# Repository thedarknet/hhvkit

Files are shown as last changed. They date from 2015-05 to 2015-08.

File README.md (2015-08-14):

hhvkit
======

DefCon 23 Hardware Hacking Village Learn To Solder Kit, by:
- Smitty, mark@halibut.com (concept, crypto, and firmware (2014))
- Krux, krux@thcnet.net (hardware)
- Cmdc0de, comc0dez@gmail.com (firmware (2015))

These are the files needed to build the firmware for the DefCon DarkNet
ID Badge that was sold as the Hardware Hacking Village's Learn To Solder
kit at DefCon 23 in 2015.

If you checkout the repo into your Arduino folder, it should just build
on Arduino v1.6.4.  

It creates the following directories:

DCDarkNet/Firmware/
- Contains the code.

DCDarkNet/Firmware/build/
- The automated build/burn system used to program over 300 chips in 
  just a couple hours. (ZIF socket not included. Some assembly required.)

libraries/IRSerial2014/
- A modified version of SoftwareSerial from Arduino 1.0 (don't know if 
  it's changed at all in 1.5) to allow for independent inverted logic
  on the Rx and Tx lines (so the idle state isn't HIGH on the IR LED
  and burn through battery), and to perform 38kHz modulation for the IR.

libraries/UsbKeyboard/
- A version of vusb-for-arduino [1] modified so it doesn't instantiate
  the USB object in the .h file and therefore immeidately upon startup.
  Instead, you instantiate the object whenever you want it and can
  delete it when you're done.
  [1] https://code.google.com/p/vusb-for-arduino/

libraries/DarkNetDisplay
- Modified version of the adafruit gfx and ssd_1306 libraries to work with our 
  darknet badge display
	https://github.com/adafruit/Adafruit-GFX-Library
	https://github.com/adafruit/Adafruit_SSD1306

Building and Burning
======

All the following commands are run inside DCDarkNet/Firmware/build/
This section is really only relevant if you are burning this code into
a whole bunch of chips.  If you're just burning your own chip, or are
playing around with different code, you're better off just using the 
Arduino IDE to program the board directly with an FTDI cable.

Preparation: GUIDs and private keys
======
The code is programmed to FLASH, but there are a few things needed in
EEPROM before the badge is functional.  If you have a chip from us, it
was already programmed with your GUID and private key, which will persist
through a re-flash.  But if you have a new chip, you'll need to program
your GUID and private key into the chip.

We don't currently (2015-08-2) have a way to generate new GUIDs and 
keys for you, nor to take in GUIDs and keys from you to put into the DB.
So you're welcome to play with this code and use it for other things, 
but unless you got a chip from us at DefCon, you won't be able to 
use your code on the live DarkNet site (https://dcdark.net.)

If you're building a whole new name space and don't need to interact 
with the DefCon DarkNet Daemon, you can generate your own DB of random
GUIDs and private keys using the build/buildDB.pl script, and redirecting
the output to a file called DB.  This doesn't actually do anything with 
the chip, it just generates random numbers and formats them correctly.

build$ ./buildDB.pl > DB

Preparation: Program
=======
All the source code is compiled down into a .hex file by Arduino. Those
who do more microcontroller work than I do can build this by hand.  I'm 
lazy and let Arduino do all the drudgery for me.

Go to preferences and enable "verbose output of the build process" or
whatever it's called.  This will make Arduino NOT delete the temporary
build directories it creates in /tmp.  Then build the code with Ctrl-R.
That will burn into /tmp/build[some number].tmp/   Find the most recent
build directory (the one that was likely just created or updated), and
copy Firmware.cpp.hex to your build/ directory:

build$ cp /tmp/build[some number].tmp/Firmware.cpp.hex .

You will have to do this EVERY TIME you build.

Burning Chips
=======
The burn-bootloader.sh script assumes you have a USBtinyISP [2].  You'll
need to modify the avr-dude command if you have a different ISP.
[2] http://www.adafruit.com/product/46

Connect the USBtinyISP to the ICSP header on your board and run:

build$ ./burn-bootloader.sh

Congrats!  Your badge is now an Arduino!  It can be programmed through
the FTDI header as if it were an Uno.

But to make it a DarkNet ID Badge, it needs the GUID and private key in 
EEPROM, and the program in flash.

The burn-eeprom.sh script takes a GUID on the command line, pulls it 
and it's associated key from the "DB" file generated above, formats
them into a .hex file that avr-dude can burn to EEPROM, and burns it.
Again, you'll need the USBtinyISP plugged into the ICSP header:

build$ ./burn-eeprom.sh GUIDGUID

After those two are done, the program can be written to flash using
the FTDI serial console cable (it's much faster than using the ICSP.)
burn-flash.sh takes the local file Firmware.cpp.hex you copied 
above.

build$ ./burn-flash.sh

Automating the Build
======
I wasn't about to run these three commands manually for 350 chips, so 
I wrote run.pl which pulls all the GUIDs from DB and cycles through 
them.  If all is happy and working, you can just run.pl, hit enter to
program a chip, swap the chip in the programming rig, hit enter again, 
lather, rinse, repeat.  It takes care of all the iteration on GUID,
as well as allows you to <N>ext and <P>rev through the DB list in case
a burn goes awry and needs to be redone.

build$ ./run.pl

BOM and Assembly Instructions
======

The Bill of Materials is located here:

https://www.mouser.com/ProjectManager/ProjectDetail.aspx?AccessID=6bc2d848d8

Assembly Instructions are located here:

- https://dcdark.net/2015/hhv-badge/
- https://dcdark.net/2015/hhv-display/

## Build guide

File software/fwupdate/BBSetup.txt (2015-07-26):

Some notes on setting up beaglebone for badge fw updates:

sudo apt-get update
sudo apt-get upgrade
sudo apt-get install avrdude

Install Adafruit_BBIO:
https://learn.adafruit.com/setting-up-io-python-library-on-beaglebone-black/installation-on-ubuntu

So root isn't needed for avrdude:
sudo ln -s $PWD/10-avrisp.rules /etc/udev/rules.d/

avrdude -v -c avrispmkII -p m328p -P usb
avrdude -v -c avrispmkII -p m328p -P usb -U flash:r:flash.bin:r

*run once in python as root (not needed if using service)*
TODO - automate this
import Adafruit_BBIO.UART as UART
UART.setup("UART4")

ls -l of files that need to be placed in /home/debian/darknet/:
-rw-r--r-- 1 debian debian  1959 Jul 26 18:01 autoupdate.py
-rw-r--r-- 1 debian debian  4775 Jul 26 18:04 AVRProg.py
-rwxr-xr-x 1 debian debian   102 Jul 26 18:02 darknet.sh
-rw-r--r-- 1 debian debian   769 Jul 26 18:05 DummyLCDController.py
-rw-r--r-- 1 debian debian 65141 Jul 26 18:02 firmware.hex
-rw-r--r-- 1 debian debian  2830 Jul 26 18:04 SFLCDController.py

Service Misc Notes:
from: https://gist.github.com/tstellanova/7323116

darknet.service goes in /lib/systemd/system/darknet.service

sudo ln -s /lib/systemd/system/darknet.service /etc/systemd/system/darknet.service

sudo systemctl daemon-reload
sudo systemctl enable darknet.service
sudo systemctl start darknet.service

sudo systemctl stop darknet.service

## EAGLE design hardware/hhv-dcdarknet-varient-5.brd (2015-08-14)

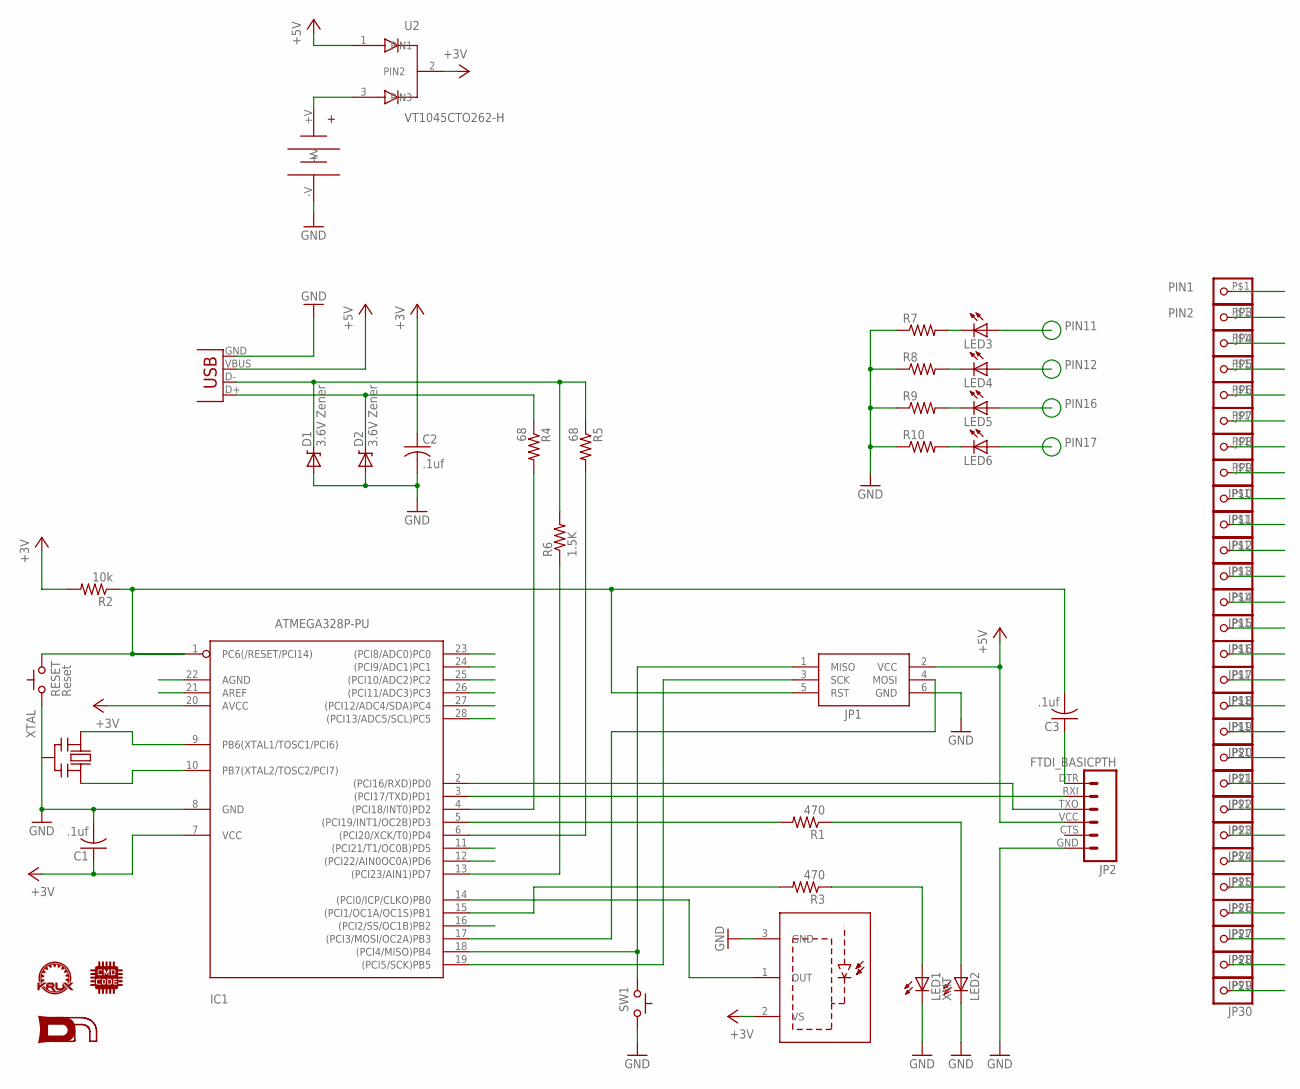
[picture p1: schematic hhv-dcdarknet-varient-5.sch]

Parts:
C1, C2, C3: .1uf; C025-030X050
D1, D2: 3.6V Zener; DIODE-ZENER
IC1: ATMEGA328P-PU; DIL28-3
JP1: JP1; AVRISP
JP2: FTDI_BASICPTH; FTDI_BASIC
JP3, JP4, JP5, JP6, JP7, JP8, JP9, JP10, JP11, JP12, JP13, JP14, JP15, JP16, JP17, JP18, JP19, JP20, JP21, JP22, JP23, JP24, JP25: PINHD-1X11X1_SQUARE; 1X1-SMALL_CUT
JP26, JP27, JP28, JP29, JP30: PINHD-1X11X1-SMALL; 1X1-SMALL
LED1: XMT; LED5MM-FLAT
LED2: LED5MM-FLAT
LED3, LED4, LED5, LED6: LED1206; LED-1206
R1, R3: 470; AXIAL-0.3
R2: 10k; AXIAL-0.3
R4, R5: 68; AXIAL-0.3
R6: 1.5K; AXIAL-0.3
R7, R8, R9, R10: RESISTOR1206; 1206
RESET: Reset; TACTILE-2PIN
SW1: SWITCH_TACTILETACTILE-2PIN; TACTILE-2PIN
U1: RCV; IR-MODULE
U2: VT1045CTO262-H; TO262-H
U$1: DN_LOGO
U$2: CMDC0DE_LOGO; CMDC0DE
U$3: KRUX_LOGO
U$5: 12BH423-GR3-CELL_NOBORDER; 3-AAA-CELL_NOBORDER
X2: USB; USB-B-PTH
XTAL: CERMOSCILL-THM; CERM_OSC

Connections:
+3V3: C1.1, C2.1, IC1.7 (VCC), IC1.20 (AVCC), JP9.P$1, JP22.P$1, R2.P$2 (2), U1.2 (VS), U2.2 (PIN2)
+5V: JP1.2 (VCC), JP2.VCC (4), U2.1 (PIN1), X2.VBUS
GND: C1.2, C2.2, D1.P$2 (A), D2.P$2 (A), IC1.8 (GND), JP1.6 (GND), JP2.GND (6), JP10.P$1, LED1.K (C), LED2.K (C), R7.1, R8.1, R9.1, R10.1, RESET.P$2 (C), SW1.P$1 (A), U1.3 (GND), U$5.-V, X2.GND, XTAL.P$2 (GND)
unnamed: C3.1, JP2.DTR (1)
unnamed: LED3.C, R7.2
unnamed: LED4.C, R8.2
unnamed: LED5.C, R9.2
unnamed: LED6.C, R10.2
unnamed: LED1.A, R3.P$1 (1)
unnamed: LED2.A, R1.P$1 (1)
unnamed: D2.P$1 (C), R4.P$1 (1), X2.D+
unnamed: U2.3 (PIN3), U$5.+V
PIN1: C3.2, IC1.1 (PC6(/RESET/PCI14)), JP1.5 (RST), JP3.P$1, R2.P$1 (1), RESET.P$1 (A)
PIN2: IC1.2 ((PCI16/RXD)PD0), JP2.TXO (3), JP4.P$1
PIN3: IC1.3 ((PCI17/TXD)PD1), JP2.RXI (2), JP5.P$1
PIN4: IC1.4 ((PCI18/INT0)PD2), JP6.P$1, R4.P$2 (2)
PIN5: IC1.5 ((PCI19/INT1/OC2B)PD3), JP7.P$1, R1.P$2 (2)
PIN6: IC1.6 ((PCI20/XCK/T0)PD4), JP8.P$1, R5.P$2 (2)
PIN9: IC1.9 (PB6(XTAL1/TOSC1/PCI6)), JP11.P$1, XTAL.P$1 (IN)
PIN10: IC1.10 (PB7(XTAL2/TOSC2/PCI7)), JP12.P$1, XTAL.P$3 (OUT)
PIN11: IC1.11 ((PCI21/T1/OC0B)PD5), JP13.P$1, LED3.A
PIN12: IC1.12 ((PCI22/AIN0OC0A)PD6), JP14.P$1, LED4.A
PIN13: IC1.13 ((PCI23/AIN1)PD7), JP15.P$1, R6.P$1 (1)
PIN14: IC1.14 ((PCI0/ICP/CLKO)PB0), JP16.P$1, U1.1 (OUT)
PIN15: IC1.15 ((PCI1/OC1A/OC1S)PB1), JP17.P$1, R3.P$2 (2)
PIN16: IC1.16 ((PCI2/SS/OC1B)PB2), JP18.P$1, LED5.A
PIN17: IC1.17 ((PCI3/MOSI/OC2A)PB3), JP1.4 (MOSI), JP19.P$1, LED6.A
PIN18: IC1.18 ((PCI4/MISO)PB4), JP1.1 (MISO), JP20.P$1, SW1.P$2 (C)
PIN19: IC1.19 ((PCI5/SCK)PB5), JP1.3 (SCK), JP21.P$1
PIN21: IC1.21 (AREF), JP23.P$1
PIN22: IC1.22 (AGND), JP24.P$1
PIN23: IC1.23 ((PCI8/ADC0)PC0), JP25.P$1
PIN24: IC1.24 ((PCI9/ADC1)PC1), JP26.P$1
PIN25: IC1.25 ((PCI10/ADC2)PC2), JP27.P$1
PIN26: IC1.26 ((PCI11/ADC3)PC3), JP28.P$1
PIN27: IC1.27 ((PCI12/ADC4/SDA)PC4), JP29.P$1
PIN28: IC1.28 ((PCI13/ADC5/SCL)PC5), JP30.P$1
USB: D1.P$1 (C), R5.P$1 (1), R6.P$2 (2), X2.D-

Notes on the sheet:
PIN11
PIN12
PIN16
PIN17

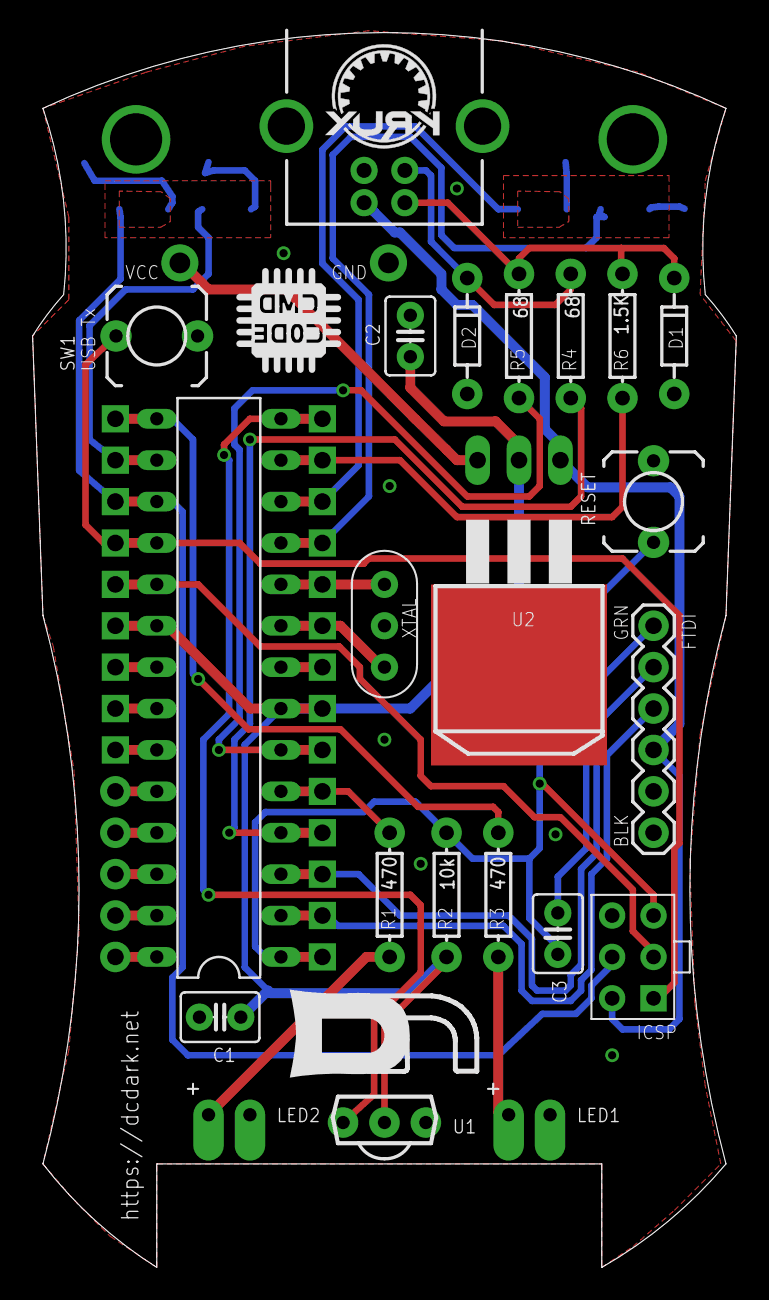
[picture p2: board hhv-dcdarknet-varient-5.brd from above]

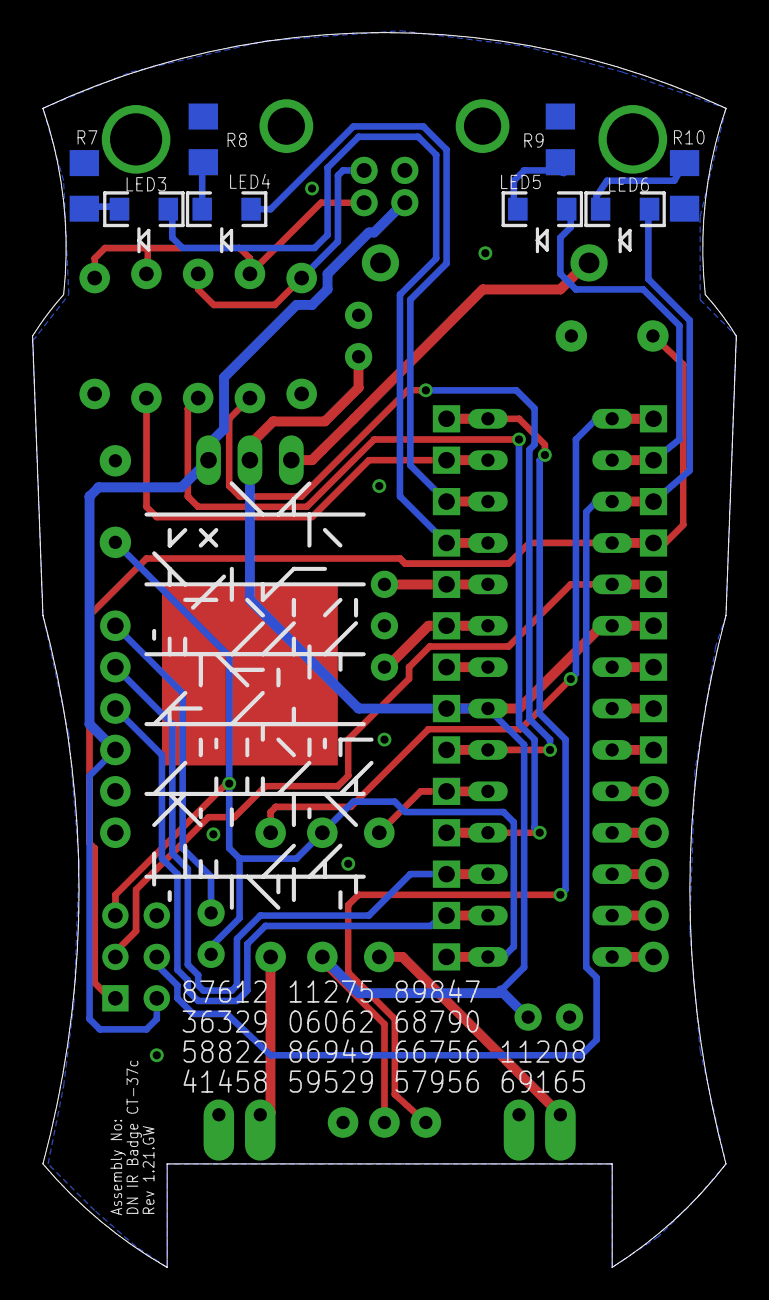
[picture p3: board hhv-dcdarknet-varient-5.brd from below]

Board: 2 copper layers, 43.2 x 75.8 mm, 62 parts (10 on the bottom side), 38 nets.

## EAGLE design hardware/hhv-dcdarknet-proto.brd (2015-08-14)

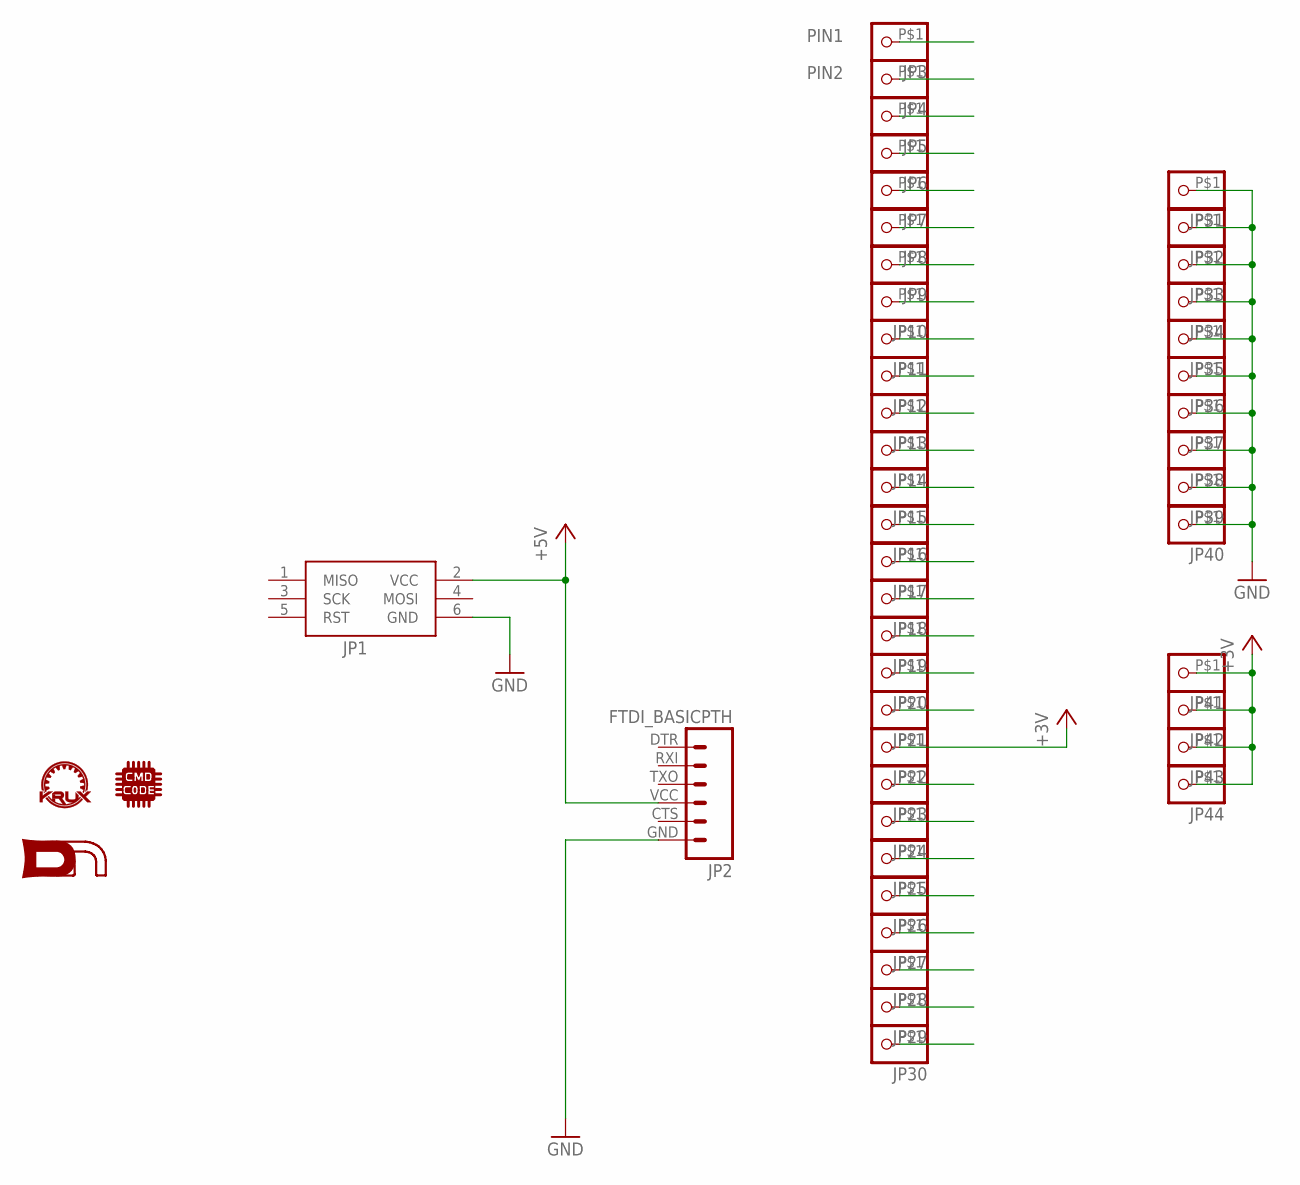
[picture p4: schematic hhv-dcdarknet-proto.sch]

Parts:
JP1: JP1; AVRISP
JP2: FTDI_BASICPTH; FTDI_BASIC
JP3, JP4, JP5, JP6, JP7, JP8, JP9, JP10, JP11, JP12, JP13, JP14, JP15, JP16, JP17, JP18, JP19, JP20, JP21, JP22, JP23, JP24, JP25, JP26, JP27, JP28, JP29, JP30, JP31, JP32, JP33, JP34, JP35, JP36, JP37, JP38, JP39, JP40, JP41, JP42, JP43, JP44: PINHD-1X11X1_SQUARE; 1X1-SMALL_CUT
U$1: KRUX_LOGO
U$2: DN_LOGO
U$3: CMDC0DE_LOGO; CMDC0DE

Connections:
+3V3: JP9.P$1, JP22.P$1, JP41.P$1, JP42.P$1, JP43.P$1, JP44.P$1
+5V: JP1.2 (VCC), JP2.VCC (4)
GND: JP1.6 (GND), JP2.GND (6), JP10.P$1, JP31.P$1, JP32.P$1, JP33.P$1, JP34.P$1, JP35.P$1, JP36.P$1, JP37.P$1, JP38.P$1, JP39.P$1, JP40.P$1
PIN1: JP3.P$1
PIN2: JP4.P$1
PIN3: JP5.P$1
PIN4: JP6.P$1
PIN5: JP7.P$1
PIN6: JP8.P$1
PIN9: JP11.P$1
PIN10: JP12.P$1
PIN11: JP13.P$1
PIN12: JP14.P$1
PIN13: JP15.P$1
PIN14: JP16.P$1
PIN15: JP17.P$1
PIN16: JP18.P$1
PIN17: JP19.P$1
PIN18: JP20.P$1
PIN19: JP21.P$1
PIN21: JP23.P$1
PIN22: JP24.P$1
PIN23: JP25.P$1
PIN24: JP26.P$1
PIN25: JP27.P$1
PIN26: JP28.P$1
PIN27: JP29.P$1
PIN28: JP30.P$1

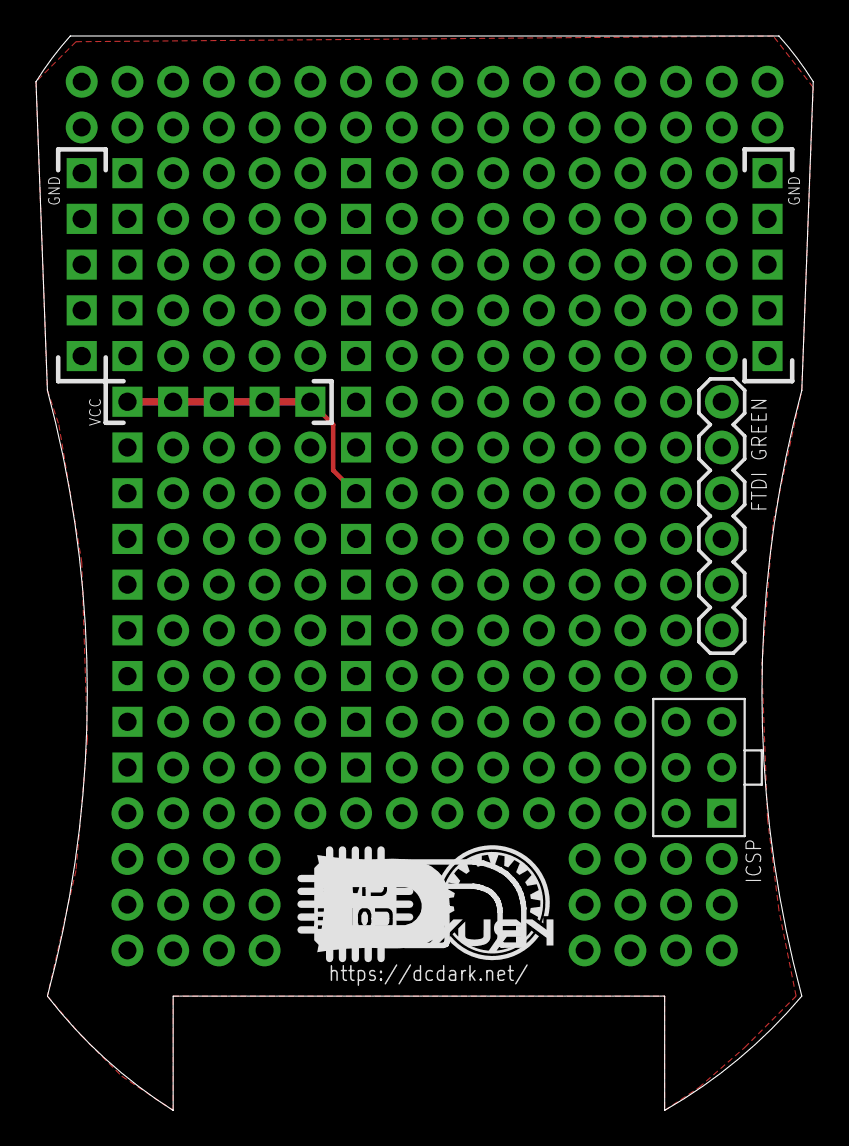
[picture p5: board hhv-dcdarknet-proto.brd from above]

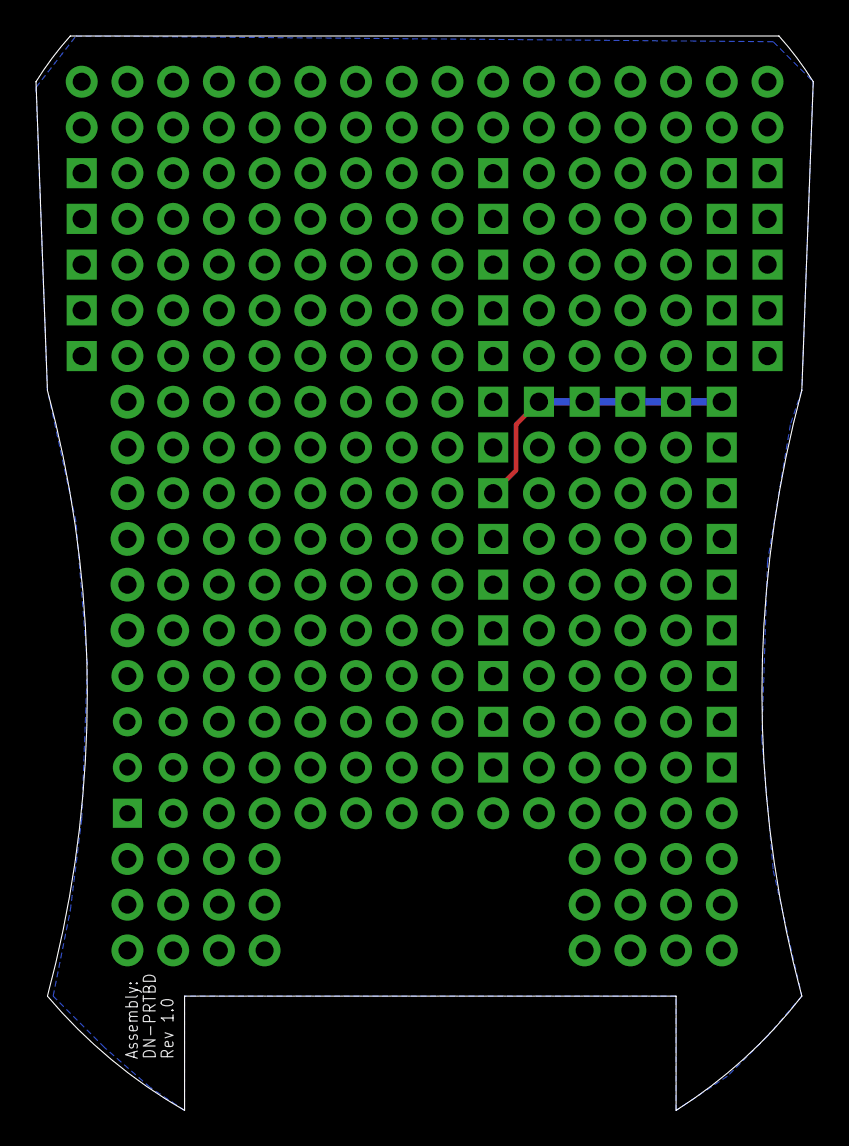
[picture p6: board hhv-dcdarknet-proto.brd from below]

Board: 2 copper layers, 43.2 x 59.7 mm, 47 parts (2 on the bottom side), 3 nets.

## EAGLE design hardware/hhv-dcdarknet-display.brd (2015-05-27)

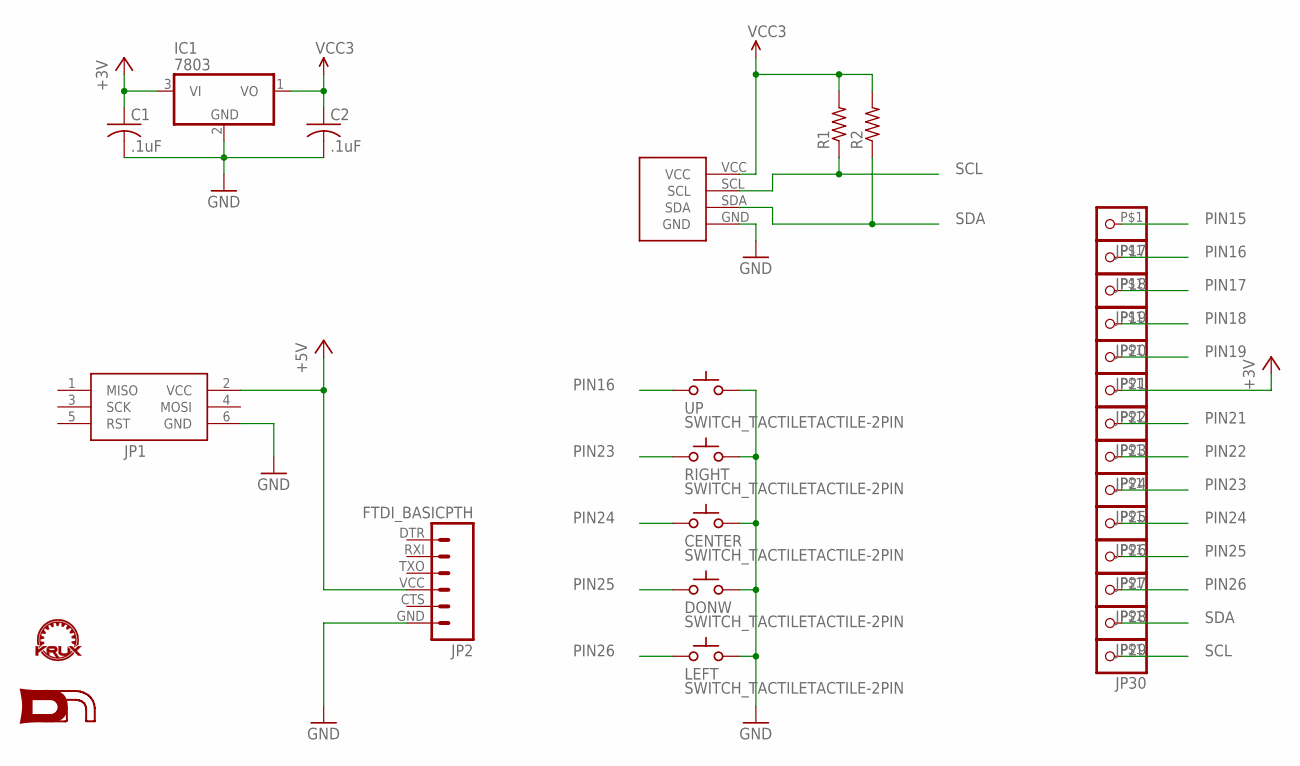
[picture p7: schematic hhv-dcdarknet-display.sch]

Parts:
C1, C2: .1uF; C025-030X050
CENTER: SWITCH_TACTILETACTILE-2PIN; TACTILE-2PIN
DONW: SWITCH_TACTILETACTILE-2PIN; TACTILE-2PIN
IC1: 7803; TO92
JP1: JP1; AVRISP
JP2: FTDI_BASICPTH; FTDI_BASIC
JP17, JP18, JP19, JP20, JP21, JP22, JP23, JP24, JP25, JP26, JP27, JP28, JP29, JP30: PINHD-1X11X1_SQUARE; 1X1-SMALL_CUT
LEFT: SWITCH_TACTILETACTILE-2PIN; TACTILE-2PIN
R1, R2: R-US_0204/5; 0204/5
RIGHT: SWITCH_TACTILETACTILE-2PIN; TACTILE-2PIN
U$1: KRUX_LOGO
U$2: DN_LOGO
U$3: I2C_0.96_OLEDOLED; I2C_0.96_OLED
UP: SWITCH_TACTILETACTILE-2PIN; TACTILE-2PIN

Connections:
+3V3: C1.1, IC1.3 (VI), JP22.P$1
+5V: JP1.2 (VCC), JP2.VCC (4)
GND: C1.2, C2.2, CENTER.P$1 (A), DONW.P$1 (A), IC1.2 (GND), JP1.6 (GND), JP2.GND (6), LEFT.P$1 (A), RIGHT.P$1 (A), U$3.GND, UP.P$1 (A)
PIN15: JP17.P$1
PIN16: JP18.P$1, UP.P$2 (C)
PIN17: JP19.P$1
PIN18: JP20.P$1
PIN19: JP21.P$1
PIN21: JP23.P$1
PIN22: JP24.P$1
PIN23: JP25.P$1, RIGHT.P$2 (C)
PIN24: CENTER.P$2 (C), JP26.P$1
PIN25: DONW.P$2 (C), JP27.P$1
PIN26: JP28.P$1, LEFT.P$2 (C)
PIN27: JP29.P$1, R2.1, U$3.SDA
PIN28: JP30.P$1, R1.1, U$3.SCL
VCC3: C2.1, IC1.1 (VO), R1.2, R2.2, U$3.VCC

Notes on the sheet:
SCL
SDA
PIN26
PIN25
PIN24
PIN23
PIN22
PIN21
PIN19
PIN18
PIN17
PIN16
PIN15

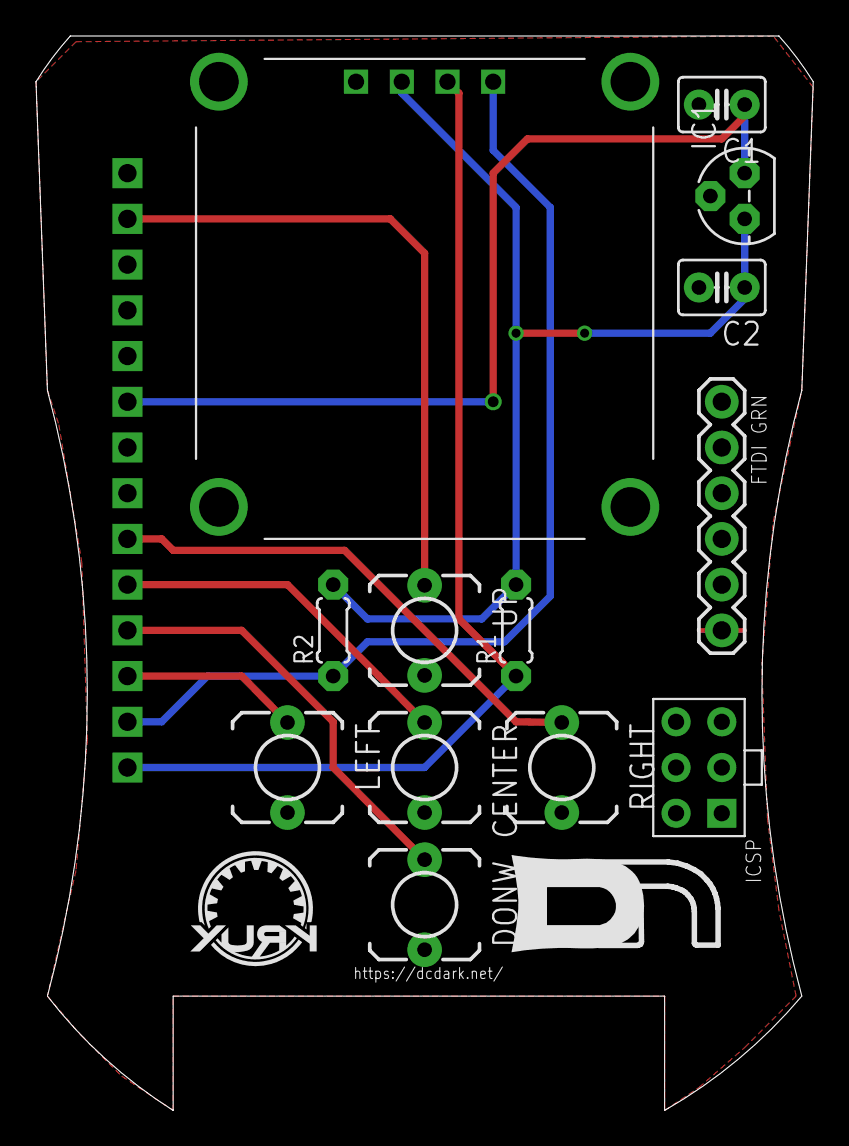
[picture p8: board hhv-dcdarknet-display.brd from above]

Board: 2 copper layers, 43.2 x 59.7 mm, 29 parts (1 on the bottom side), 11 nets.

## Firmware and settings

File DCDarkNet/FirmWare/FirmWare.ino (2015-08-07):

#include <avr/pgmspace.h>
#include "IRSerial-2014.h"
//#include "MD5.h"
#include <EEPROM.h>
#include <avr/sleep.h>
#include <Wire.h>
#include <DarkNetDisplay.h>

// USB Keyboard port
//#define USB_PUBLIC static
#include "UsbKeyboard.h"

/*
 * Pinout:
 * 0, 1: FTDI serial header
 * 2, 4, 7: USB D+, D-, Pullup (respectively)
 * 8, 9: IR Rx, Tx (respectively)
 * 3: Morse LED
 * 5, 6, 10, 11: Backlight LEDs
 * 12: Button
 * 16: Display board UP button
 * 23: Display board RIGHT button
 * 24: Display board CENTER (ENTER) button
 * 25: Display Board DOWN button
 * 26: Display Board LEFT button
 * 27: SDA
 * 28: SCL
 */
#define MAKE_ME_A_CONTEST_RUNNER 0

// IR Parameters
#define IR_RX 8
#define IR_TX 9
#define IR_BAUD 300
IRSerial irSerial(IR_RX, IR_TX, false, true);

// Console port
#define SERIAL_BAUD 115200

// Main morse LED
#define LED_PIN 3

// Switch pin
#define BUTTON_PIN 12

#define BUTTON_UP        13 //which is the 16th counted pin //wont work bc also used for backlights ops!
#define BUTTON_LEFT      A3
#define BUTTON_RIGHT     A0
#define BUTTON_DOWN      A2
#define BUTTON_CENTER    A1
#define VUP (1<<0)
#define VDOWN (1<<1)
#define VLEFT (1<<2)
#define VRIGHT (1<<3)
#define VCENTER (1<<4)

// Backlight LEDs
#define BACKLIGHT_4 5
#define BACKLIGHT_3 6
#define BACKLIGHT_2 10
#define BACKLIGHT_1 11


//BEGIN SERIAL EPIC VARS
//bool to see if we have started the SerialEpic
#define MAX_SERIAL_EPIC_TIME_MS 30000
#define MAX_SERIAL_ANSWER_LENGTH 10


//END SERIAL EPIC VARS

// BEGIN STRINGS
//string that starts serial epic
static const char* START_SERIAL_EPIC_STRING = "JOSHUA";
//static const char* SERIAL_PORT_ANSWER = "42";
#define SERIAL_PORT_QUESTION F("What is the answer to all things?")
//length of serial string
#define MIN_SERIAL_LEN  6
#define SEND_TO_DAEMON F("Send this to daemon: ")
#define DisplayEpicText F("Who started the \nDC Dark Net?")
static const char* DisplayEpicAnswer = "SMITTY";
#define iKnowNot F("I know not what you speak of.")
#define sendTheCodes F("https://dcdark.net/  Send the following codes:\n")
static const char* const PROGMEM LINE1 = "ABCDEFGHIJKLMNOPQRSTUVWXYZ 0123456789!*#@%";
#define LINE1_LENGTH 42
#define EMPTY_STR F("")
#define DKN F("DKN-")
// END REPEATED STRINGS

//BEGIN GLOBAL VARS:
//We are getting tight on space so I'm packing variables as tightly as I can
struct _PackedVars {
  uint32_t InSerialEpic : 1;
  uint32_t AwaitingSerialAnswer: 1;
  uint32_t DisplayAnswer:1;
  uint32_t LEDMode : 4; //what start up mode are we need (animation)
  uint32_t Silent : 1;
  uint32_t LINE1Loc : 6;
  uint32_t AnswerPos : 4;
  uint32_t hasSilk1 : 1;
  uint32_t hasSilk2 : 1;
  uint32_t hasSilk3 : 1;
  uint32_t isContestRunner : 1;
  uint32_t swapKeyAndGUID : 1;
  uint32_t modeInit : 1;
} PackedVars;

uint16_t KEY[4];
char GUID[9];
unsigned long nextBeacon;
#define OLED_RESET 4
DarkNetDisplay Display(OLED_RESET);
//END GLOBAL VARS


//BEGIN MODE_DEFS
#define MODE_COUNT 9
#define MODE_MORSE_CODE_EPIC     0
#define MODE_SNORING             1
#define MODE_SERIAL_EPIC         2
#define MODE_DISPLAY_BOARD_EPIC  3
#define MODE_JUST_A_COOL_DISPLAY   4
#define MODE_SILK_SCREEN           5
#define MODE_UBER_BADGE_SYNC       6
#define MODE_BACKLIGHT             7
#define MODE_SHUTDOWN              8
//END MODE DEFS


// BEGIN EEPROM count location
#define MSG_COUNT_ADDR 1022
#define RESET_STATE_ADDR 1020
#define GUID_ADDR 1012
#define KEY_ADDR 1004

// Maximum number of messages
#define MAX_NUM_MSGS 60
#define GUID_SIZE 8
#define MORSE_CODE_ENCODED_MSG 8
#define TOTAL_STORAGE_SIZE_MSG (GUID_SIZE+MORSE_CODE_ENCODED_MSG)
#define MAX_MSG_ADDR                     (TOTAL_STORAGE_SIZE_MSG*MAX_NUM_MSGS) //960
#define START_EPIC_RUN_TIME_STORAGE       MAX_MSG_ADDR+20 //cushion 980
#define UBER_CRYTPO_CONTEST_RUNNER_ADDR   START_EPIC_RUN_TIME_STORAGE //first 8 bytes uber contest runner KEY then GUID
#define MAX_EPIC_RUN_TIME_STORAGE         START_EPIC_RUN_TIME_STORAGE+16

// END EEPROM COUNT LOCATION

#define ENDLINE F("\n")

// Morse Code constants
unsigned char const morse[28] PROGMEM = {
   0x05,   // A  .-     00000101
   0x18,   // B  -...   00011000
   0x1A,   // C  -.-.   00011010
   0x0C,   // D  -..    00001100
   0x02,   // E  .      00000010
   0x12,   // F  ..-.   00010010
   0x0E,   // G  --.    00001110
   0x10,   // H  ....   00010000
   0x04,   // I  ..     00000100
   0x17,   // J  .---   00010111
   0x0D,   // K  -.-    00001101
   0x14,   // L  .-..   00010100
   0x07,   // M  --     00000111
   0x06,   // N  -.     00000110
   0x0F,   // O  ---    00001111
   0x16,   // P  .--.   00010110
   0x1D,   // Q  --.-   00011101
   0x0A,   // R  .-.    00001010
   0x08,   // S  ...    00001000
   0x03,   // T  -      00000011
   0x09,   // U  ..-    00001001
   0x11,   // V  ...-   00010001
   0x0B,   // W  .--    00001011
   0x19,   // X  -..-   00011001
   0x1B,   // Y  -.--   00011011
   0x1C,   // Z  --..   00011100
   0x01,   // space     00000001
   0x5A,   // @  .--.-. 01011010
};

//debugging macros
//#define SERIAL_TRACE 
#ifdef SERIAL_TRACE
  #define SERIAL_TRACE_LN(a) Serial.println(a);
  #define SERIAL_TRACE(a) Serial.print(a);
#else
  #define SERIAL_TRACE_LN(a)
  #define SERIAL_TRACE(a)
#endif

//#define SERIAL_INFO 
#ifdef SERIAL_INFO
  #define SERIAL_INFO_LN(a) Serial.println(a);
  #define SERIAL_INFO(a) Serial.print(a);
#else
  #define SERIAL_INFO_LN(a)
  #define SERIAL_INFO(a)
#endif
//end debugging macros


void readContestRunnerKeyAndGUID() {
#if MAKE_ME_A_CONTEST_RUNNER //make contest runner badge
  // Pull GUID and Private key from EEPROM
  for (uchar ndx = 0; ndx < 8; ndx++) {
    GUID[ndx] = EEPROM.read(UBER_CRYTPO_CONTEST_RUNNER_ADDR + 8 + ndx);
  }
  GUID[8] = 0;
  // Yes, this is big endian. I don't want to have to byte-swap
  // when building the EEPROM file from text strings.
  KEY[0] = (EEPROM.read(UBER_CRYTPO_CONTEST_RUNNER_ADDR + 0) << 8) + EEPROM.read(UBER_CRYTPO_CONTEST_RUNNER_ADDR + 1);
  KEY[1] = (EEPROM.read(UBER_CRYTPO_CONTEST_RUNNER_ADDR + 2) << 8) + EEPROM.read(UBER_CRYTPO_CONTEST_RUNNER_ADDR + 3);
  KEY[2] = (EEPROM.read(UBER_CRYTPO_CONTEST_RUNNER_ADDR + 4) << 8) + EEPROM.read(UBER_CRYTPO_CONTEST_RUNNER_ADDR + 5);
  KEY[3] = (EEPROM.read(UBER_CRYTPO_CONTEST_RUNNER_ADDR + 6) << 8) + EEPROM.read(UBER_CRYTPO_CONTEST_RUNNER_ADDR + 7);
#endif
}

void readInGUIDAndKey() {
  for (uchar ndx = 0; ndx < 8; ndx++) {
    GUID[ndx] = EEPROM.read(GUID_ADDR + ndx);
  }
  GUID[8] = 0;
  // Yes, this is big endian. I don't want to have to byte-swap
  // when building the EEPROM file from text strings.
  KEY[0] = (EEPROM.read(KEY_ADDR + 0) << 8) + EEPROM.read(KEY_ADDR + 1);
  KEY[1] = (EEPROM.read(KEY_ADDR + 2) << 8) + EEPROM.read(KEY_ADDR + 3);
  KEY[2] = (EEPROM.read(KEY_ADDR + 4) << 8) + EEPROM.read(KEY_ADDR + 5);
  KEY[3] = (EEPROM.read(KEY_ADDR + 6) << 8) + EEPROM.read(KEY_ADDR + 7);
}

/* This is the workhorse function.  Whatever you do elsewhere,
 * When you're not working you need to call this so it looks
 * for IR data and acts on it if received.  The Rx ISR has a
 * 64 byte buffer, so you need to call this at least once every
 * (1 sec/300 symbols * 10 symbos/1 byte * 64 byte buffer = )
 * 2.13 seconds before you risk overflowing the buffer, but I'd
 * make sure you call it more often than that.  Basically,
 * whenever you are pausing, use this instead of delay().
 *
 * Like delay(), but looks for IR serial data while waiting.
 * Delays for pauseFor milliseconds.  Tight loops around looking
 * for serial data.  Also triggers a USB dump if the button is
 * pressed.
 * 
 * IMPORTANT: If either a full Serial frame is received, or the
 * button is pressed, then delayAndReadIR() can delay for much
 * longer than pauseFor milliseconds as it either handles the USB,
 * or handles a received IR signal.
 */
void delayAndReadIR(int pauseFor) {
  pauseFor = pauseFor>0?pauseFor:0;
  uint32_t returnTime = millis() + pauseFor;
  while (millis() < returnTime) {
    if (digitalRead(BUTTON_PIN) == LOW) {
      long buttonStart = millis();
      while(digitalRead(BUTTON_PIN) == LOW) {
        if (millis() - buttonStart > 2000) {
          buttonStart = 0;  // Flag to not dump USB
          break;
        }
      }
      if (buttonStart) {
        // Dump database to USB
        dumpDatabaseToUSB();
      }
    }
    int ret;
    if (ret = irSerial.available()) {
      processIR(irSerial.read());
    }
  }
}

// Sends our GUID out over the IR.  Call this "often" 
// when it's convenient in your animation. It'll handle
// dealing with the timing, whether it's been long enough
// to send another beacon.
void beaconGUID(void) {
  if (millis() >= nextBeacon) {
    if(!PackedVars.Silent) {
      Serial.println(F("Ping!"));
    }
    if (1 == PackedVars.swapKeyAndGUID) {
      readContestRunnerKeyAndGUID();
    }
    // Add a little randomness so devices don't get sync'd up.
    // Will beacon on average every 5 seconds.
    nextBeacon = millis() + random(4000, 6000);
    irSerial.print(F("0x"));
    irSerial.println(GUID);
  }
}

// The length of one morse code symbol (one "dit", and 
// the spaces between dits and dashes.)
void MorsePause(int ndx) {
  delayAndReadIR(ndx*250);
}

// Blink a character in morse code.
void sendMorse(uint8_t chr) {
  uint8_t bit;
  
  if (chr == ' ')
    chr = pgm_read_byte(morse + 26);
  else if (chr == '@')
    chr = pgm_read_byte(morse + 27);
  else if (chr >= 'A' && chr <= 'Z')
    chr = pgm_read_byte(morse + (chr-'A'));
  else {
    digitalWrite(LED_PIN, HIGH);
    MorsePause(15);
    digitalWrite(LED_PIN, LOW);
    return;
  }
  
  // Get rid of padding, looking for the start bit.
  for (bit = 0; bit < 8 && (chr & 0x80) == 0; bit++, chr<<=1)
    ;
    
  // Pass the start bit, then send the rest of the char in morse
  for (bit++, chr<<=1; bit < 8; bit++, chr<<=1) {
    digitalWrite(LED_PIN, HIGH);
    digitalWrite(BACKLIGHT_1, HIGH);
    if (chr & 0x80) {
      digitalWrite(BACKLIGHT_2, HIGH);
      digitalWrite(BACKLIGHT_3, HIGH);
      digitalWrite(BACKLIGHT_4, HIGH);
      MorsePause(3);
    } else {
      MorsePause(1);
    }
    digitalWrite(LED_PIN, LOW);
    digitalWrite(BACKLIGHT_1, LOW);
    digitalWrite(BACKLIGHT_2, LOW);
    digitalWrite(BACKLIGHT_3, LOW);
    digitalWrite(BACKLIGHT_4, LOW);
    MorsePause(1);
  }
  MorsePause(4);  // Inter character pause
}

void sendMorseStr(const __FlashStringHelper *str) {
  PGM_P p = reinterpret_cast<PGM_P>(str);
  while (1) {
    unsigned char c = pgm_read_byte(p++);
    if(c==0) break;
    sendMorse(c);
    beaconGUID();
  }
}

void sendMorseStr(const char *msg) {
  for (; *msg != '\0'; msg++) {
    sendMorse(*msg);
    beaconGUID();
  }
}

// LULZ Twitter. That's old school...  Haven't used Twitter for this since 2012.
void sendMorseTwitter(uint16_t msgAddr) {
  sendMorseStr(F("DKN DASH "));
  for (unsigned char ndx = 0; ndx < 8; ndx++) {
    sendMorse(EEPROM.read(msgAddr+ndx));
  }
}

void sendSerialTwitter(uint16_t msgAddr) {
  Serial.print(DKN);
  for (unsigned char ndx = 0; ndx < 16; ndx++) {
    Serial.write(EEPROM.read(msgAddr+ndx));
  }
  Serial.println(EMPTY_STR);
}
  
// TEA (known to be broken) with all word sizes cut in half (64 bit key, 32 bit blocks)
// Yes, I'm inviting people to hack this if they want. :-)
// TODO: Since we're giving up on backward compatability in 2014, should we increase this size?
void encrypt(uint16_t *v) {
  uint16_t v0=v[0], v1=v[1], sum=0, i;           // set up
  uint16_t delta=0x9e37;                         // a key schedule constant
  for (i=0; i < 32; i++) {                       // basic cycle start
    sum += delta;
    v0 += ((v1<<4) + KEY[0]) ^ (v1 + sum) ^ ((v1>>5) + KEY[1]);
    v1 += ((v0<<4) + KEY[2]) ^ (v0 + sum) ^ ((v0>>5) + KEY[3]);  
  }                                              /* end cycle */
  v[0]=v0; v[1]=v1;
}

uint16_t getNumMsgs() {
  return (EEPROM.read(MSG_COUNT_ADDR)<<8) + EEPROM.read(MSG_COUNT_ADDR+1);
}

void writeNumMsgs(uint16_t numMsgs) {
  EEPROM.write(MSG_COUNT_ADDR, numMsgs/256);
  EEPROM.write(MSG_COUNT_ADDR+1, numMsgs%256);
}  

bool isNumMsgsValid(uint16_t numMsgs) {
  return numMsgs < MAX_NUM_MSGS;
}

// Writes a pairing code to EEPROM
int writeEEPROM(unsigned char *guid, uint8_t *msg) {
  char msgStr[9];
  intToStr(msg, msgStr);
  
  uint16_t numMsgs = getNumMsgs();
  if (!isNumMsgsValid(numMsgs)) {
    Serial.print(F("numMsgs not valid. Setting to 0. Ignore if this is your first pairing."));
    Serial.println(numMsgs);
    // Assume this is the first read of this chip and initialize
    numMsgs = 0;
  }
  
  int msgAddr;
  unsigned char ndx;
  for (msgAddr = 0; msgAddr < numMsgs*TOTAL_STORAGE_SIZE_MSG; msgAddr+=TOTAL_STORAGE_SIZE_MSG) {
    for (ndx = 0; ndx < 8; ndx++) {
      if (guid[ndx] != EEPROM.read(msgAddr+ndx))
        break;
    }
    if (ndx == 8) {
      // Found a match.  Rewrite in case it was wrong before
      break;
    }
  }

  if (ndx != 8) {  
    // FIXME This doens't properly stop at 60. It wraps around.
    if (numMsgs > 0 && !isNumMsgsValid(numMsgs)) {
      // The DB is full.  Don't actually create a new entry.
      for (ndx = 0; ndx < 16; ndx++) {
        // Randy Quaid is my hero.
        EEPROM.write(msgAddr+ndx, "SHITTERS FULL..."[ndx]);
      }
      return msgAddr;
    } 
    else {
      numMsgs++;
    }
  }
  
  for (ndx = 0; ndx < 8; ndx++) {
    EEPROM.write(msgAddr+ndx, guid[ndx]);
    EEPROM.write(msgAddr+8+ndx, msgStr[ndx]);
  }
  writeNumMsgs(numMsgs);
  return msgAddr;
}
  

// This is our receive buffer, for data we pull out of the
// IRSerial library.  This is _NOT_ the buffer the IRSerial
// library is using to receive bytes into.
// Our buffer only needs to be big enough to hold a staza
// to process.  Right now (2014) that's 12 bytes.  I'm over-sizing
// 'cuz why not?
#define RX_BUF_SIZE 32
unsigned char rxBuf[RX_BUF_SIZE];
unsigned char head;

// Increments a pointer into rxBuf, wrapping as appropriate.
unsigned char inc(unsigned char *p) {
  unsigned char q = *p;
  *p = (*p+1) % RX_BUF_SIZE;
  return q;
}

// Returns the character in rxBuf[] that is p bytes offset from head.
// Deals with wrapping.  You'll probably want to pass a negative
// number as p.
unsigned char rxBufNdx(unsigned char p) {
  return rxBuf[(head+p)%RX_BUF_SIZE];
}
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
void loop() {
  static uint8_t count = 0;
  if((count%20)==0) {
    dumpDatabaseToSerial();  // Dump DB to serial
  }
  uint32_t start;

  if (PackedVars.LEDMode == MODE_MORSE_CODE_EPIC) { // Normal Morse code
    Serial.println(F("Begin Mode: 0"));
    //Display.fillCircle(Display.width()/2, Display.height()/2, 20, WHITE);
    //Display.display();
    sendMorseStr(F("HHVMORSE DASH "));
    sendMorseStr(GUID);
    sendMorseStr(F("HTTPS COLON SLASH SLASH DCDARK DOT NET    SEND CODES"));
    uint16_t numMsgs = getNumMsgs();
    if (isNumMsgsValid(numMsgs)) {
      for (int msgAddr = 0; msgAddr < numMsgs*16; msgAddr+=16) {
        dumpDatabaseToSerial();
        sendMorseTwitter(msgAddr);
      }
    }
  } else if (PackedVars.LEDMode == MODE_SNORING) { // Snoring mode
    Serial.println(F("Begin Mode: 1"));
    start = millis();
    rampLED(0, 248, 0, 124, 0, 124, 0, 124, 0, 124, 1600);
    rampLED(248, 0, 124, 0, 124, 0, 124, 0, 124, 0, 1600);
    beaconGUID();
    delayAndReadIR(5000-(millis()-start));
  } else if (PackedVars.LEDMode == MODE_BACKLIGHT) {  
    start = millis();
    // Lub
    rampLED(0, 200, 0, 0, 0, 0, 0, 0, 0, 0, 60);
    rampLED(200, 0, 0, 0, 0, 0, 0, 0, 0, 0, 120);
    delayAndReadIR(400);

    // Dub
    //      LED  LED  BACK 1    BACK 2    BACK 3    BACK 4
    rampLED(0,   250, 0,   0,   0,   0,   0,   0,   0,   0,   60);
    rampLED(250, 0,   0,   0,   0,   250, 0,   250, 0,   0,   120);
    rampLED(0,   0,   0,   250, 250, 150, 250, 150, 0,   250, 120);
    rampLED(0,   0,   250, 150, 150, 50,  150, 50,  250, 150, 120);
    rampLED(0,   0,   150, 100, 50,  0,   50,  0,   150, 100, 300);
    //todo check to see if this one still cashes crash every once in a while
    rampLED(0,   0,   100, 0,   0,   0,   0,   0,   100, 0,   500);
      
    beaconGUID();
    delayAndReadIR(4000-(millis()-start));
  } else if (PackedVars.LEDMode == MODE_SERIAL_EPIC) {
    unsigned long SerialEpicTimer = millis();
    PackedVars.Silent = 1;
    Serial.println(F("Password: "));
    while((millis()-SerialEpicTimer) < MAX_SERIAL_EPIC_TIME_MS ) { //don't loop for MAX_SERIAL_EPIC_TIME
      start = millis();
      if(0==PackedVars.InSerialEpic) {
        if( Serial.available()>0) { //are we trying to enter the serial epic?
          if(Serial.available()==MIN_SERIAL_LEN) {
            for(short n = 0; n<MIN_SERIAL_LEN;n++) {
              char s = toupper(Serial.read());
              if(s==START_SERIAL_EPIC_STRING[n]) {
                PackedVars.InSerialEpic = 1;  
              }
            }
          } else {
            Serial.println(iKnowNot);
            PackedVars.InSerialEpic = 0;
          }
        }
      } else {
        if(0==PackedVars.AwaitingSerialAnswer) { //send question
          //Serial.println(F("What is the answer to all things?"));
          PackedVars.AwaitingSerialAnswer = 1;
          GenerateResponseToCorrectEpic(START_SERIAL_EPIC_STRING,false);
        } else {
          #if 0
          if(Serial.available()) {
            PackedVars.AwaitingSerialAnswer = 0;
            if(Serial.available() == strlen(SERIAL_PORT_ANSWER)) {
              char serialAnswer[MAX_SERIAL_ANSWER_LENGTH+1] = {'\0'};
              short i = 0;
              while(Serial.available()) {
                serialAnswer[i++] = Serial.read();
              }
              //Serial.println((char *)&serialAnswer[0]);
              if(strcmp(SERIAL_PORT_ANSWER,&serialAnswer[0])==0) {
                GenerateResponseToCorrectEpic(SERIAL_PORT_ANSWER,false);
                break;
              } else {
                Serial.println(iKnowNot);
              }
            } else {
              Serial.println(iKnowNot);
            }
          }
          #endif
        }
      }
      drainSerial();
      beaconGUID();
      delayAndReadIR(1000-(millis()-start));
    }
    if((millis()-SerialEpicTimer) >= MAX_SERIAL_EPIC_TIME_MS) {
      Serial.println(F("Times up."));
    }
    PackedVars.InSerialEpic = 0;
    PackedVars.AwaitingSerialAnswer = 0;
  } else if(PackedVars.LEDMode == MODE_DISPLAY_BOARD_EPIC) {
    if(!PackedVars.DisplayAnswer) {
      start = millis();
      static char Answer[10] = {'\0'};
      static uint8_t count = 0;
      Display.setTextWrap(true);
      //Serial.println(digitalRead(BUTTON_UP)==LOW);
      //Serial.println(analogRead(BUTTON_LEFT));
      //Serial.println(analogRead(BUTTON_RIGHT));
      //Serial.println(analogRead(BUTTON_DOWN));
      //Serial.println(analogRead(BUTTON_CENTER));
      uint16_t b1 = ( (digitalRead(BUTTON_UP)==LOW?:0) | 
          (analogRead(BUTTON_LEFT)<10?VLEFT:0) | 
          (analogRead(BUTTON_RIGHT)<10?VRIGHT:0) | 
          (analogRead(BUTTON_DOWN)<10?VDOWN:0) | 
          (analogRead(BUTTON_CENTER)<10?VCENTER:0));
      delay(4);
      
      uint16_t button = b1 & ( (digitalRead(BUTTON_UP)==LOW?VUP:0) | 
        (analogRead(BUTTON_LEFT)<10?VLEFT:0) | (analogRead(BUTTON_RIGHT)<10?VRIGHT:0) | 
        (analogRead(BUTTON_DOWN)<10?VDOWN:0) | (analogRead(BUTTON_CENTER)<10?VCENTER:0));
      
      if(button&VLEFT) {
        PackedVars.LINE1Loc = PackedVars.LINE1Loc==0?LINE1_LENGTH-1:PackedVars.LINE1Loc-1;
      } 
      if(button&VRIGHT) {
        PackedVars.LINE1Loc = ++PackedVars.LINE1Loc%LINE1_LENGTH;
      }
      if(button&VUP) {
        short tmp = PackedVars.LINE1Loc-LINE1_LENGTH;
        if(tmp<0) {
         PackedVars.LINE1Loc=LINE1_LENGTH+PackedVars.LINE1Loc; 
        } else {
         PackedVars.LINE1Loc=tmp; 
        }
      }
      if(button&VDOWN) {
        PackedVars.LINE1Loc = (PackedVars.LINE1Loc+LINE1_LENGTH/2)%LINE1_LENGTH;
      }
      
      if(button==(VRIGHT|VLEFT)) {
         memset(&Answer[0],0,sizeof(Answer)); 
         PackedVars.AnswerPos = 0;
         PackedVars.LINE1Loc = 0;
      }
      
      if(button&VCENTER) {
        Answer[PackedVars.AnswerPos] = LINE1[PackedVars.LINE1Loc];
        PackedVars.AnswerPos = (PackedVars.AnswerPos+1)>=sizeof(Answer) ? sizeof(Answer) : PackedVars.AnswerPos+1;
      }
      
      if(strcmp(&Answer[0],&DisplayEpicAnswer[0])==0) {
        Display.clearDisplay();
        Display.setCursor(0,0);
        PackedVars.DisplayAnswer = 1;
        GenerateResponseToCorrectEpic(&DisplayEpicAnswer[0],true);
        //GenerateResponseToCorrectEpic(Questions[STANDARD_SERIAL_EPIC].Answer,true);
        Display.display();
      } else {
        //Serial.println(&Answer[0]);
        uint8_t location = 0;
        Display.setCursor(0,0);
        Display.println(DisplayEpicText);
        Display.println(EMPTY_STR);
        Display.println(EMPTY_STR);
        Display.print(&Answer[0]);
        if((++count)&0x1) {
          Display.println("_");
        } else {
          Display.println(LINE1[PackedVars.LINE1Loc]);
        }
        Display.println(EMPTY_STR);
        Display.println(LINE1);
        Display.display();
        delay(20);
      }
    }
    //8/3 DAC turning off the ability to sync IR with another bade in this mode
    //beaconGUID();
    delayAndReadIR(400);
    
  } else if (PackedVars.LEDMode == MODE_SILK_SCREEN) { 
    PackedVars.Silent = 1;
    if(0==count) {
      Serial.println(F("Enter the sequence: "));
    }
    //fibonacci numbers
    char silkBuffer[6] = {0};
    if(Serial.available()>0) {
      for(int i=0;i<sizeof(silkBuffer)-1;i++) {
        if(Serial.available()) {
          silkBuffer[i] = Serial.read();
        }
      }
      //Serial.println(&silkBuffer[0]);
      uint32_t num = atoi(&silkBuffer[0]);
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

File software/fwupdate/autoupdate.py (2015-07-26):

#!/usr/bin/python
# 
# Test program to update DCDarkNet badges using avrdude in FTDI(arduino) mode
# 
# 
import Adafruit_BBIO.GPIO as GPIO
import Adafruit_BBIO.UART as UART
import SFLCDController
import AVRProg
import os.path
import time
import sys

DEBUG = False

def readFlash():
    print('Reading flash')
    flashFile = AVRProg.readFlash(DEBUG)
    if flashFile:
        print('Flash dumped to: ' + flashFile)
    else:
        print('Error reading flash')

def flashFirmware(filename):
    lcd.clear();
    lcd.write('Flashing FW')

    rval = AVRProg.runAvrdudeCommand('avrdude -v -c ' + AVRProg.PROGRAMMER + ' -p m328p -P ' + AVRProg.PROGRAMMERS[AVRProg.PROGRAMMER] + ' -Uflash:w:' + filename + ':i', DEBUG)
    if rval == 1:
        print('Error flashing firmware')
        lcd.clear()
        lcd.write("ERROR: could not flash firmware")
        return rval
    else:
        print('Flashed firmware successfully!')
        lcd.clear()
        lcd.write("Success!!!")

    return 0

def waitForButton(pin):
    # 
    # Debounce!
    # 
    pushed = False
    while not pushed:    
        GPIO.wait_for_edge(pin, GPIO.FALLING)
        time.sleep(0.033)
        if (GPIO.input(pin) == 0):
            pushed = True

# 
# Start Here!
# 
if len(sys.argv) < 2:
    print('Usage: ' + sys.argv[0] + ' /path/to/firmware.bin')
    sys.exit(1)

GPIO.setup('P9_12', GPIO.IN)
UART.setup("UART4")

# 
# Setup LCD
# 
lcd = SFLCDController.Controller()
lcd.connect('/dev/ttyO4', 9600)
lcd.clear()

AVRProg.lcd = lcd
AVRProg.PROGRAMMER = 'arduino'

if os.path.exists('/dev/ttyUSB0') is False:
    lcd.clear()
    lcd.write('DCDarkNet ERR:  no /dev/ttyUSB0')
    
while os.path.exists('/dev/ttyUSB0') is False:
    time.sleep(5)

# TODO - add updater/error count
while True:
    lcd.clear()
    lcd.write('DCDarkNet - Push to update FW')
    waitForButton('P9_12')
    flashFirmware(sys.argv[1])
    time.sleep(5)
    # TODO - add animation here

lcd.disconnect()

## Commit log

2014-08-11 Added schematic and board files. (Eagle format.)
    [hhv-dcdarknet.brd, hhv-dcdarknet.sch]
2015-03-09 Created 2015 branch Renamed IR_Quest_2014 to Firmware added calibration on reset to usb For me this took an old netbook from never working with the badget to 'sort of working', I can get up to 3 star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
    Next check in I plan to remove tv_b_gone check in
    Next check in I will try the continueous calibration (if possible, it only works if D+ is connected to the interrupt and I have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
    [FirmWare.ino, UsbKeyboardTest.ino]
2015-05-08 updated config data to say 2015 Added defines so we can turn off and on serial debugging quickly Updated USB Key board test to work with calibration code
2015-05-11 Update hhv-dcdarknet.brd
    Updated version for DC23. Adjustments on layout and increased pad sizes and spacing. Silk screen has not been updated yet.
    [hhv-dcdarknet.brd]
2015-05-11 Update hhv-dcdarknet.sch
    Updated board for DC23.
    [hhv-dcdarknet.sch]
2015-05-11 hhv-dcdarknet-display.brd
    Display daughter board addon
    [hhv-dcdarknet-display.brd]
2015-05-11 hhv-dcdarknet-display.sch
    Display daughter board schematic
    [hhv-dcdarknet-display.sch]
2015-05-30 issue 3: Functionally complete
    Needed to be Done done done:
    1) Current the password is set to cmdc0de
    Will this work for the story? If not what should it be
    2) Current the question is: What is the answer to all things?
    You should know the answer
    [FirmWare.ino]
2015-05-30 Added support for AVR dragon and FTDI/arduino NOTE: EEPROM doesn't seem to work with arduino mode
    [updater.py]
2015-05-30 Adding misc notes and BeagleBone UART setup script
2015-06-01 initial check in for display board, just libraries and some minor code refactoring As well as test code for display
2015-06-03 Added 'autodetect' feature that checks all programmers to see if a device is connected. Once it finds one, it proceeds
2015-06-03 Cleanup error message and make sure we return 1 when unsuccessfully exiting
    [updater.py]
2015-06-04 Adding modeFlashBootloader which works if the AVR is on a badge (avr dragon doesn't have oscillator...)
    [updater.py]
2015-07-05 issue 15 finally complete!
    [ButtonTest.ino, FirmWare.ino]
2015-07-11 added back the backlight led ramps reduced global memory by nearly another 100 bytes
2015-07-18 serial port epic updated so that you no longer answer the question 'what is the answer to all things'? and the password was chaged from cmdc0de to JOSHUA
    Now if your firmware is burned with MAKE_ME_A_CONTEST_RUNNER defined to anything but 0 you can put your badge into mode 7 and
    read display for instructions on how to complete the 6 part silk screen crypto for the agent. The agent will get a special GUID sent to them
    that will be used for yet another badge specific validation string for the server
    [FirmWare.ino]
2015-07-26 Check that there's an FTDI device plugged in
2015-08-03 ensure that when we print out the validate code that a number less than 16 is still 2 characters in the hexstring
2015-08-04 up the ir serial buffer back to 32 bytes 14 is too tight
    [FirmWare.ino]
2015-08-04 tweaked timeing on display epic fixed over read on serial
    [FirmWare.ino]
2015-08-05 fixed bad serial output
    [FirmWare.ino]
2015-08-06 fixed a serial output bug
    [FirmWare.ino]
2015-08-14 Updated Eagle files for the 2015 boards.
    [hhv-dcdarknet-display.sch, hhv-dcdarknet-proto.brd, hhv-dcdarknet-proto.sch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]

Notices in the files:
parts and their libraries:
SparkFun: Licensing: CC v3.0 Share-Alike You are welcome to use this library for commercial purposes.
